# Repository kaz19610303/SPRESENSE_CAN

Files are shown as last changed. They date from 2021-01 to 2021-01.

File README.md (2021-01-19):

# SPRESENSE_CAN
Sony Spresense用の***CANインターフェースボード***です。　　
  
このボードに使用しているCANインタフェースICは***Microchip***社の***MCP2515T-E_ST***です。  
MCP2515は、第2世代のスタンドアロンCANコントローラです。MCP2510とピンおよび機能の互換性があり、より高速なスループット、データバイト・フィルタリング、タイムトリガー・プロトコルのサポートなどのアップグレードされた機能が含まれています。  
詳しくは以下のデータシートをご覧下さい。  
[MCP2515 データシート](https://www.mouser.jp/datasheet/2/268/MCP2515-Stand-Alone-CAN-Controller-with-SPI-200018-708845.pdf)  
  
回路図とEagle用のデータはGithubにて公開しています。  
[kaz19610303/SPRESENSE_CAN](https://github.com/kaz19610303/SPRESENSE_CAN)  
  
ジャンパー設定  
SJ1　INTピン選択　1: EMMC_DATA2　3:I2S_LRCK  
SJ2　csピン選択　 1: I2S_DIN　   3:SPI_CS  
SJ3　ショートで終端抵抗有効

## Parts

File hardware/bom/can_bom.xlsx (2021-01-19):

Parts | Qty | Value | Package | Description | MANUFACTURER_NAME | MANUFACTURER_PART_NUMBER
C1, C2 | 2 | 4.7uF +/-10% 10V | C0603K | CAPACITOR, European symbol | Samsung Electro-Mechanics | CL10A475KP8NNNC
C3, C7 | 2 | 10uF +/-10% 10V | C0603 | 302010142 | Yageo | CC0603JRNPO9BN270
C4, C8 | 2 | 1uF +/-10% 10V | C0603K | CAPACITOR, European symbol | Taiyo Yuden | LMK107B7105KA-T
C5, C6 | 2 | 18pF +/-1% 10V | C0603 | 302010142 | Yageo | CC0603JRNPO9BN270
C9 | 1 | 0.1uF+/-10% 10V | C0603K | CAPACITOR, European symbol | Taiyo Yuden | EMK063BJ104MP-F
IC1 | 1 | TXB0106RGYR | SN74CBT3257CRGYR | Translation - Voltage Levels 8B Bidirec Vltg-Lev Translator | Texas Instruments | TXB0106RGYR
IC2 | 1 | MCP2515T-E_ST | SOP65P640X120-20N | CAN Interface IC W/ SPI Inter 125dC | Microchip | MCP2515T-E/ST
IC3 | 1 | MCP1700T-3302E_TT | SOT95P237X112-3N | LDO voltage regulator 250mA Isupply 1uA | Microchip | MCP1700T-3302E/TT
IC4 | 1 | MCP2551T-E_SN | SOIC127P600X175-8N | CAN Interface IC Hi Spd CAN Transceiv | Microchip | MCP2551T-E/SN
J1 | 1 | 1776112-2 | SHDR2W90P0X348_1X2_700X730X850 | Conn Eurostyle Block 2 POS 3.5mm Solder ST Thru-Hole 12A/Contact | TE Connectivity | 1776112-2
R1, R2, R3 | 3 | 10K +/-5% 1/10W | R0603 | 301010293 | Yageo | RC0603JR-0710KL
R4 | 1 | 120 +/-5% 1/10W | R0603 | 301010293 | Yageo | RC0603JR-7W120RL
X1 | 1 | 8Mhz | HC49UP | SMD Crystal 8Mhz-18pF-20ppm-40R;HC49UP | ECS | ECS-080-18-5PX-JES-TR
JP1, JP2 | 2 | JUMPER-SMT_3_NO_NO-SILK | SMT-JUMPER_3_NO_NO-SILK | Normally open jumper
JP3 | 1 | JUMPER-SMT_2_NC_PASTE_NO-SILK | SMT-JUMPER_2_NC_PASTE_NO-SILK | Normally closed solder jumper
SV1, SV2 | 2 |  | FE13 | FEMALE HEADER

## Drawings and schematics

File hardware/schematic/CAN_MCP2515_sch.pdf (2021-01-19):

# 13 SV2

# 13 SV1 A¹

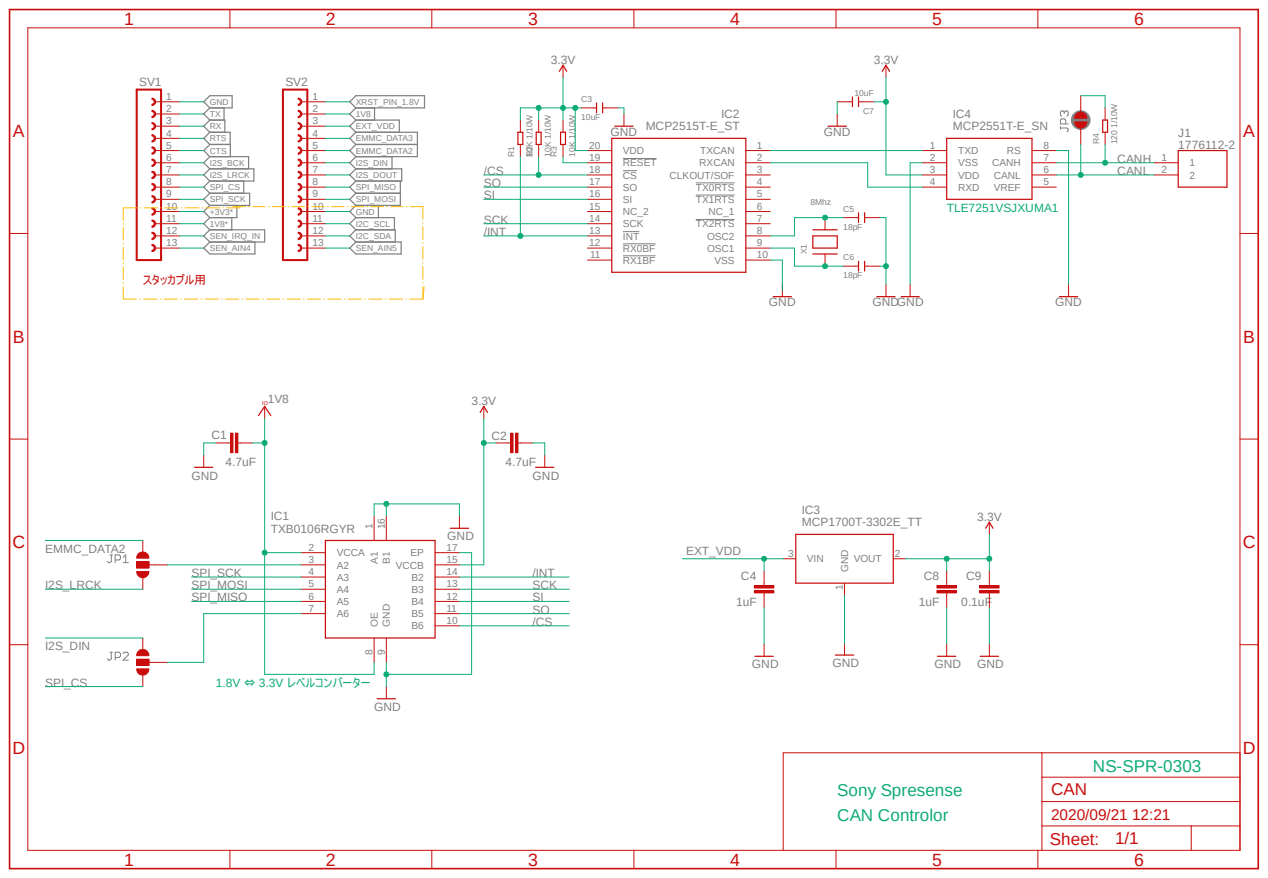
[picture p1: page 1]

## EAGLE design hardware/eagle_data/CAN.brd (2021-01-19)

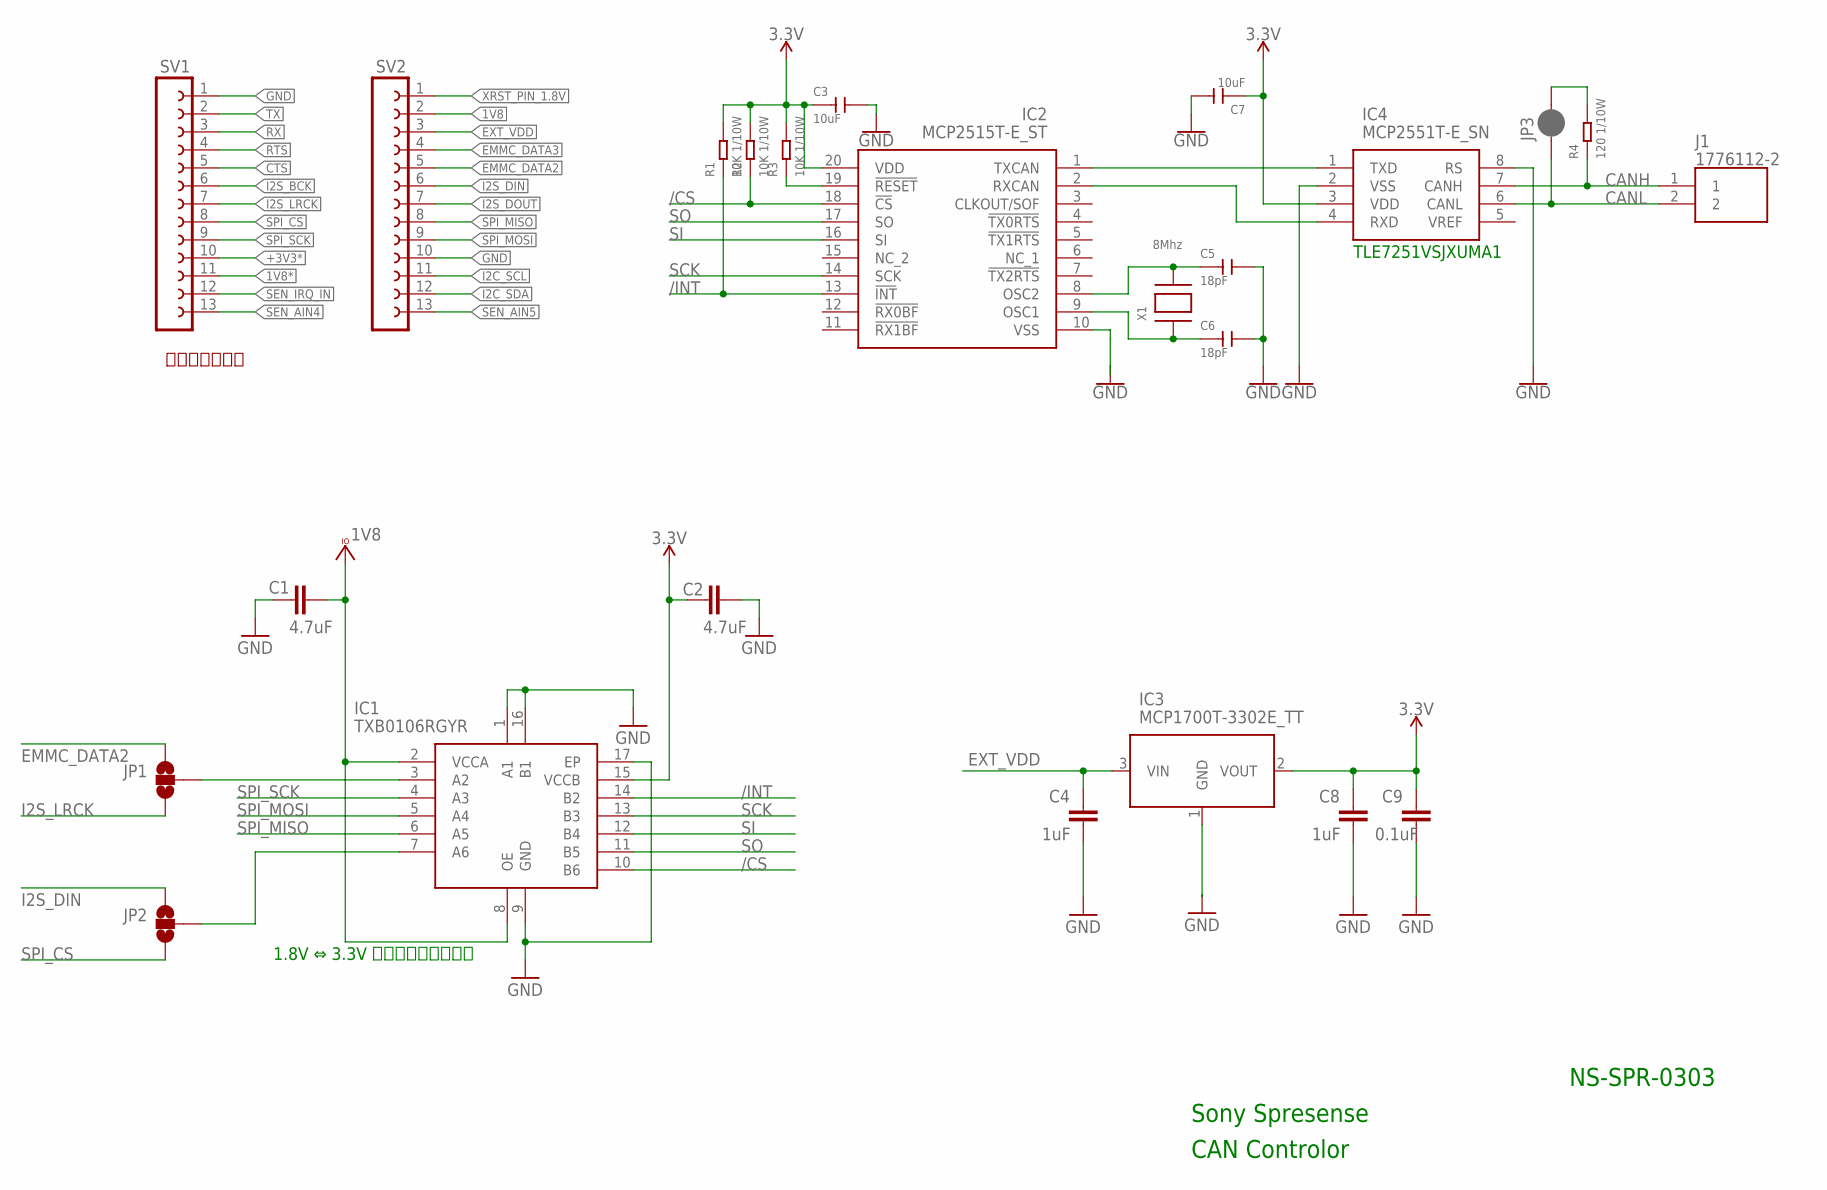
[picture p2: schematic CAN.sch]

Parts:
C1, C2: 4.7uF; C0603K
C3, C7: 10uF; C0603
C4, C8: 1uF; C0603K
C5, C6: 18pF; C0603
C9: 0.1uF; C0603K
IC1: TXB0106RGYR; SN74CBT3257CRGYR
IC2: MCP2515T-E_ST; SOP65P640X120-20N
IC3: MCP1700T-3302E_TT; SOT95P237X112-3N
IC4: MCP2551T-E_SN; SOIC127P600X175-8N
J1: 1776112-2; SHDR2W90P0X348_1X2_700X730X850
JP1, JP2: JUMPER-SMT_3_NO_NO-SILK; SMT-JUMPER_3_NO_NO-SILK
JP3: JUMPER-SMT_2_NC_PASTE_NO-SILK; SMT-JUMPER_2_NC_PASTE_NO-SILK
R1, R2, R3: 10K 1/10W; R0603
R4: 120 1/10W; R0603
SV1, SV2: FE13-1; FE13
X1: 8Mhz; HC49UP

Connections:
1V8: C1.2, IC1.2 (VCCA), IC1.8 (OE), SV2.2
1V8*: SV1.11
3.3V: C2.1, C3.1, C7.1, C8.1, C9.1, IC1.15 (VCCB), IC2.20 (VDD), IC3.2 (VOUT), IC4.3 (VDD), R1.2, R2.2, R3.2
+3V3*: SV1.10
/CS: IC1.10 (B6), IC2.18 (!CS), R2.1
/INT: IC1.14 (B2), IC2.13 (!INT), R1.1
CANH: IC4.7 (CANH), J1.1, R4.1
CANL: IC4.6 (CANL), J1.2, JP3.1
CTS: SV1.5
EMMC_DATA2: JP1.1, SV2.5
EMMC_DATA3: SV2.4
EXT_VDD: C4.1, IC3.3 (VIN), SV2.3
GND: C1.1, C2.2, C3.2, C4.2, C5.2, C6.2, C7.2, C8.2, C9.2, IC1.1 (A1), IC1.9 (GND), IC1.16 (B1), IC1.17 (EP), IC2.10 (VSS), IC3.1 (GND), IC4.2 (VSS), IC4.8 (RS), SV1.1, SV2.10
I2C_SCL: SV2.11
I2C_SDA: SV2.12
I2S_BCK: SV1.6
I2S_DIN: JP2.1, SV2.6
I2S_DOUT: SV2.7
I2S_LRCK: JP1.3, SV1.7
unnamed: IC2.1 (TXCAN), IC4.1 (TXD)
unnamed: IC2.2 (RXCAN), IC4.4 (RXD)
unnamed: IC1.7 (A6), JP2.2
unnamed: IC1.3 (A2), JP1.2
unnamed: C5.1, IC2.8 (OSC2), X1.P$2
unnamed: C6.1, IC2.9 (OSC1), X1.P$1
unnamed: JP3.2, R4.2
unnamed: IC2.19 (!RESET), R3.1
RTS: SV1.4
RX: SV1.3
SCK: IC1.13 (B3), IC2.14 (SCK)
SEN_AIN4: SV1.13
SEN_AIN5: SV2.13
SEN_IRQ_IN: SV1.12
SI: IC1.12 (B4), IC2.16 (SI)
SO: IC1.11 (B5), IC2.17 (SO)
SPI_CS: JP2.3, SV1.8
SPI_MISO: IC1.6 (A5), SV2.8
SPI_MOSI: IC1.5 (A4), SV2.9
SPI_SCK: IC1.4 (A3), SV1.9
TX: SV1.2
XRST_PIN_1.8V: SV2.1

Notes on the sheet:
1.8V ⇔ 3.3V レベルコンバーター
スタッカブル用
CAN Controlor
Sony Spresense
NS-SPR-0303
TLE7251VSJXUMA1

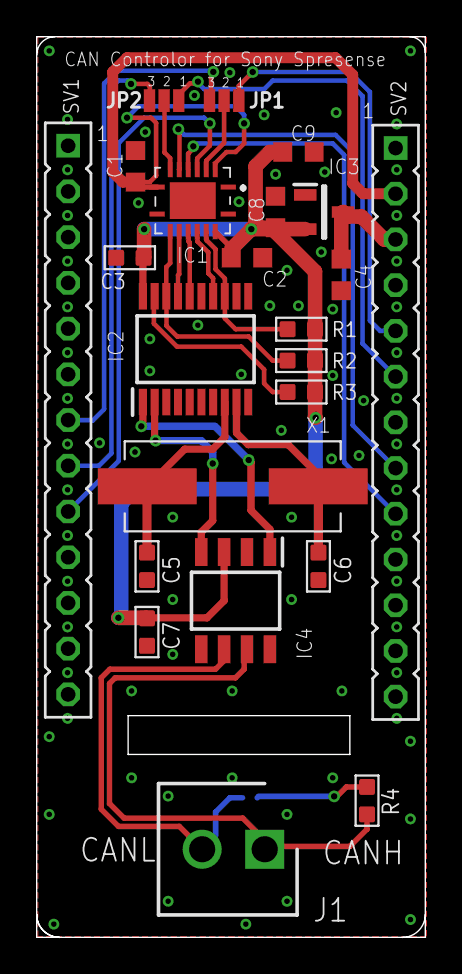
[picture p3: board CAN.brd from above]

Board: 2 copper layers, 21.6 x 50.0 mm, 24 parts (1 on the bottom side), 26 nets.

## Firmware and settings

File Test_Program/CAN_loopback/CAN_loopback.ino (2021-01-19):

/* CAN Loopback Example
 * This example sends a message once a second and receives that message
 *   no CAN bus is required.  This example will test the functionality 
 *   of the protocol controller, and connections to it.
 *   
 *   Written By: Cory J. Fowler - October 5th 2016
 */

#include "mcp_can.h"
#include <SPI.h>

// CAN TX Variables
unsigned long prevTX = 0;                                        // Variable to store last execution time
const unsigned int invlTX = 1000;                                // One second interval constant
byte data[] = {0xAA, 0x55, 0x01, 0x10, 0xFF, 0x12, 0x34, 0x56};  // Generic CAN data to send

// CAN RX Variables
long unsigned int rxId;
unsigned char len;
unsigned char rxBuf[8];

// Serial Output String Buffer
char msgString[128];

// CAN0 INT and CS
#define CAN0_INT 20                              // Set INT to pin 2 -> 20
MCP_CAN CAN0(19);                               // Set CS to pin 10  -> 19


void setup()
{
  Serial.begin(115200);  // CAN is running at 500,000BPS; 115,200BPS is SLOW, not FAST, thus 9600 is crippling.
  
  // Initialize MCP2515 running at 16MHz with a baudrate of 500kb/s and the masks and filters disabled.
  if(CAN0.begin(MCP_ANY, CAN_500KBPS, MCP_16MHZ) == CAN_OK)
    Serial.println("MCP2515 Initialized Successfully!");
  else
    Serial.println("Error Initializing MCP2515...");
  
  // Since we do not set NORMAL mode, we are in loopback mode by default.
  //CAN0.setMode(MCP_NORMAL);

  pinMode(CAN0_INT, INPUT);                           // Configuring pin for /INT input
  
  Serial.println("MCP2515 Library Loopback Example...");
}

void loop()
{
  if(!digitalRead(CAN0_INT))                          // If CAN0_INT pin is low, read receive buffer
  {
    CAN0.readMsgBuf(&rxId, &len, rxBuf);              // Read data: len = data length, buf = data byte(s)
    
    if((rxId & 0x80000000) == 0x80000000)             // Determine if ID is standard (11 bits) or extended (29 bits)
      sprintf(msgString, "Extended ID: 0x%.8lX  DLC: %1d  Data:", (rxId & 0x1FFFFFFF), len);
    else
      sprintf(msgString, "Standard ID: 0x%.3lX       DLC: %1d  Data:", rxId, len);
  
    Serial.print(msgString);
  
    if((rxId & 0x40000000) == 0x40000000){            // Determine if message is a remote request frame.
      sprintf(msgString, " REMOTE REQUEST FRAME");
      Serial.print(msgString);
    } else {
      for(byte i = 0; i<len; i++){
        sprintf(msgString, " 0x%.2X", rxBuf[i]);
        Serial.print(msgString);
      }
    }
        
    Serial.println();
  }
  
  if(millis() - prevTX >= invlTX){                    // Send this at a one second interval. 
    prevTX = millis();
    byte sndStat = CAN0.sendMsgBuf(0x100, 8, data);
    
    if(sndStat == CAN_OK)
      Serial.println("Message Sent Successfully!");
    else
      Serial.println("Error Sending Message...");

  }
}

/*********************************************************************************************************
  END FILE
*********************************************************************************************************/

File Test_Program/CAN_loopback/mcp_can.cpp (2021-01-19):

/*
  mcp_can.cpp
  2012 Copyright (c) Seeed Technology Inc.  All right reserved.
  2017 Copyright (c) Cory J. Fowler  All Rights Reserved.

  Author: Loovee
  Contributor: Cory J. Fowler
  2017-09-25
  This library is free software; you can redistribute it and/or
  modify it under the terms of the GNU Lesser General Public
  License as published by the Free Software Foundation; either
  version 2.1 of the License, or (at your option) any later version.

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
  You should have received a copy of the GNU Lesser General Public
  License along with this library; if not, write to the Free Software
  Foundation, Inc., 51 Franklin St, Fifth Floor, Boston, MA  02110-
  1301  USA
*/
#include "mcp_can.h"

#define spi_readwrite SPI5.transfer
#define spi_read() spi_readwrite(0x00)

/*********************************************************************************************************
** Function name:           mcp2515_reset
** Descriptions:            Performs a software reset
*********************************************************************************************************/
void MCP_CAN::mcp2515_reset(void)                                      
{
    SPI5.beginTransaction(SPISettings(10000000, MSBFIRST, SPI_MODE0));
    MCP2515_SELECT();
    spi_readwrite(MCP_RESET);
    MCP2515_UNSELECT();
    SPI5.endTransaction();
    delayMicroseconds(10);
}

/*********************************************************************************************************
** Function name:           mcp2515_readRegister
** Descriptions:            Read data register
*********************************************************************************************************/
INT8U MCP_CAN::mcp2515_readRegister(const INT8U address)                                                                     
{
    INT8U ret;

    SPI5.beginTransaction(SPISettings(10000000, MSBFIRST, SPI_MODE0));
    MCP2515_SELECT();
    spi_readwrite(MCP_READ);
    spi_readwrite(address);
    ret = spi_read();
    MCP2515_UNSELECT();
    SPI5.endTransaction();

    return ret;
}

/*********************************************************************************************************
** Function name:           mcp2515_readRegisterS
** Descriptions:            Reads sucessive data registers
*********************************************************************************************************/
void MCP_CAN::mcp2515_readRegisterS(const INT8U address, INT8U values[], const INT8U n)
{
    INT8U i;
    SPI5.beginTransaction(SPISettings(10000000, MSBFIRST, SPI_MODE0));
    MCP2515_SELECT();
    spi_readwrite(MCP_READ);
    spi_readwrite(address);
    // mcp2515 has auto-increment of address-pointer
    for (i=0; i<n; i++) 
        values[i] = spi_read();

    MCP2515_UNSELECT();
    SPI5.endTransaction();
}

/*********************************************************************************************************
** Function name:           mcp2515_setRegister
** Descriptions:            Sets data register
*********************************************************************************************************/
void MCP_CAN::mcp2515_setRegister(const INT8U address, const INT8U value)
{
    SPI5.beginTransaction(SPISettings(10000000, MSBFIRST, SPI_MODE0));
    MCP2515_SELECT();
    spi_readwrite(MCP_WRITE);
    spi_readwrite(address);
    spi_readwrite(value);
    MCP2515_UNSELECT();
    SPI5.endTransaction();
}

/*********************************************************************************************************
** Function name:           mcp2515_setRegisterS
** Descriptions:            Sets sucessive data registers
*********************************************************************************************************/
void MCP_CAN::mcp2515_setRegisterS(const INT8U address, const INT8U values[], const INT8U n)
{
    INT8U i;
    SPI5.beginTransaction(SPISettings(10000000, MSBFIRST, SPI_MODE0));
    MCP2515_SELECT();
    spi_readwrite(MCP_WRITE);
    spi_readwrite(address);
       
    for (i=0; i<n; i++) 
        spi_readwrite(values[i]);
	
    MCP2515_UNSELECT();
    SPI5.endTransaction();
}

/*********************************************************************************************************
** Function name:           mcp2515_modifyRegister
** Descriptions:            Sets specific bits of a register
*********************************************************************************************************/
void MCP_CAN::mcp2515_modifyRegister(const INT8U address, const INT8U mask, const INT8U data)
{
    SPI5.beginTransaction(SPISettings(10000000, MSBFIRST, SPI_MODE0));
    MCP2515_SELECT();
    spi_readwrite(MCP_BITMOD);
    spi_readwrite(address);
    spi_readwrite(mask);
    spi_readwrite(data);
    MCP2515_UNSELECT();
    SPI5.endTransaction();
}

/*********************************************************************************************************
** Function name:           mcp2515_readStatus
** Descriptions:            Reads status register
*********************************************************************************************************/
INT8U MCP_CAN::mcp2515_readStatus(void)                             
{
    INT8U i;
    SPI5.beginTransaction(SPISettings(10000000, MSBFIRST, SPI_MODE0));
    MCP2515_SELECT();
    spi_readwrite(MCP_READ_STATUS);
    i = spi_read();
    MCP2515_UNSELECT();
    SPI5.endTransaction();
    return i;
}

/*********************************************************************************************************
** Function name:           setMode
** Descriptions:            Sets control mode
*********************************************************************************************************/
INT8U MCP_CAN::setMode(const INT8U opMode)
{
    mcpMode = opMode;
    return mcp2515_setCANCTRL_Mode(mcpMode);
}

/*********************************************************************************************************
** Function name:           mcp2515_setCANCTRL_Mode
** Descriptions:            Set control mode
*********************************************************************************************************/
INT8U MCP_CAN::mcp2515_setCANCTRL_Mode(const INT8U newmode)
{
    INT8U i;

    mcp2515_modifyRegister(MCP_CANCTRL, MODE_MASK, newmode);

    i = mcp2515_readRegister(MCP_CANCTRL);
    i &= MODE_MASK;

    if ( i == newmode ) 
        return MCP2515_OK;

    return MCP2515_FAIL;
}
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

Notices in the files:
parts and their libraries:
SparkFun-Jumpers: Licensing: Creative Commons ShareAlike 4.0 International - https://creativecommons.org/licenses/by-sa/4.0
